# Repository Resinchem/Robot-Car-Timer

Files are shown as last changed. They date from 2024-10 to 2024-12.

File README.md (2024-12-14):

## Robot Car Race Timer System
The project was developed as a simple automatic timing system for 6th grade computer science robot car races, but has many other potential uses.

MainPage

It uses and ESP32, MAX7219 display and VL53L0X sensors to determine when an object crosses the start or finish line and starts or stops the timer (with 0.1 second resolution), shown on the matrix display.  Use of the VL53L0X distance sensors instead of motion allows movement around and near the 'race course' without triggering the sensors.  Optional LED lighting is also synced to the start, active and end race stages.

The full version includes WiFi onboarding, a web interface for some settings and over-the-air (OTA) updates for future firmwware releases.  Note that support for the no-WiFi version was dropped beginning with version 0.22.  If you truly need a version that does not require or use WiFi, please see [release 0.21](https://github.com/Resinchem/Robot-Car-Timer/releases/tag/v0.21), which was the last version that supported a -noWiFi version.

You can watch a video on the build process here: [ESP32 Build: An Automated Timing System for Robot Racers](https://youtu.be/EBmh5WEJYhU)

Please refer to the [wiki](https://github.com/Resinchem/Robot-Car-Timer/wiki) for full information, including installation, setup, options and use of the system.

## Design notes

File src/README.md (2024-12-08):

### If you just want to install the firmware on your ESP32, you do not need to download the source code!
Just download the latest **RobotCarTimer_vx.xx_ESP32.bin** file from the [Releases page](https://github.com/Resinchem/Robot-Car-Timer/releases) and follow the installation and instructions that are found in the [wiki](https://github.com/Resinchem/Robot-Car-Timer/wiki).  Please try the steps in the wiki before posting questions about how to install the firmware.

## Source Code
Two versions of the source code are available.  _You only need one source code file!_

**racecar_timer.ino**

_This is the recommended version._ It contains all the features, including the ability to make changes to some options and settings using a web interface and to perform over-the-air (OTA) updates of the firmware wirelessly.  This is the only version supported after v0.21.

**racecar_nowifi.ino** (v0.21 and earlier only)

This version should only be used if the intended installation location does not have WiFi available.  It obviously does not include any sort of web interface and therefore any changes to the settings and options require editing the source code, recompiling and then uploading via the Arduino IDE or other compatible application.  And since over-the-air updates are not available without WiFi, each update or change requires connecting the controller to a PC/USB port for uploading.  _Releases of the software after v0.21 do not include a non-WiFi version!_

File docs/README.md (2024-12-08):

### This document contains much of the same information that can be found in the Wiki.

It is provided as a dowloadable version for potential use or easier access when building/using the system.  This document is current as of the v0.25 release **but may not be updated with future versions**.

Note that you must download and/or open this document outside of Github for any of the embedded links in the document to function.  This includes the links found in the table of contents.

#### Always refer to the Wiki and version release notes for the most current information!

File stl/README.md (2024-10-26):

### 3D Printed Parts
A few optional 3D printed enclosure design files are provided here.  Note that use of 3D printed parts is _entirely optional_ and is not required for system functionality.  You can substitue project boxes or omit enclosures altogether.

All enclosures were printed with PLA.  **Supports are highly recommended for all parts**.

#### Controller Enclosure
ControllerEnclosure_Small

A simple enclosure for the ESP32 controller.  Designed for a standard 1/2 size ElectroCookie solderable breadboard with height to accommodate pin headers.  Mounting posts that accept M2 screws elevates the ElectroCookie board so that wiring may be completed on the top or bottom of the board.

#### MAX7219 Timer Enclosure
TimerEnclosure_small

The timer enclosure not only houses the MAX7219 dot-matrix display, but also the push buttons and toggle switch for the system.  The MAX7219 should pressure fit, but if it is loose or tends to fall out, just a couple of spots of hot glue on the vertical back supports will keep the display in place but still allow it to be removed if necessary.

#### VL53L0X Mount
VL53L0X_Mount_small

This mount provides a mounting bracket that allows the VL53L0X to be mounted while still allowing vertical and horizontal adjustments so that sensor can be precisely aligned with the start/finish lines.  It is a slightly remixed version of the [original version by Speedfreek01 via Thingiverse](https://www.thingiverse.com/thing:4511170).

_These files are provided "as-is" and unfortunately I cannot modify or print parts for individual use._

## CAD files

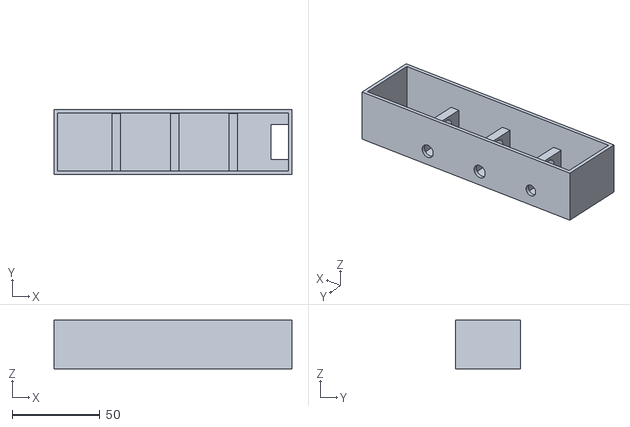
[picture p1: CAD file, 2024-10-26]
stl/MAX7219 Timer Enclosure.stl
136.0 x 37.0 x 28.0

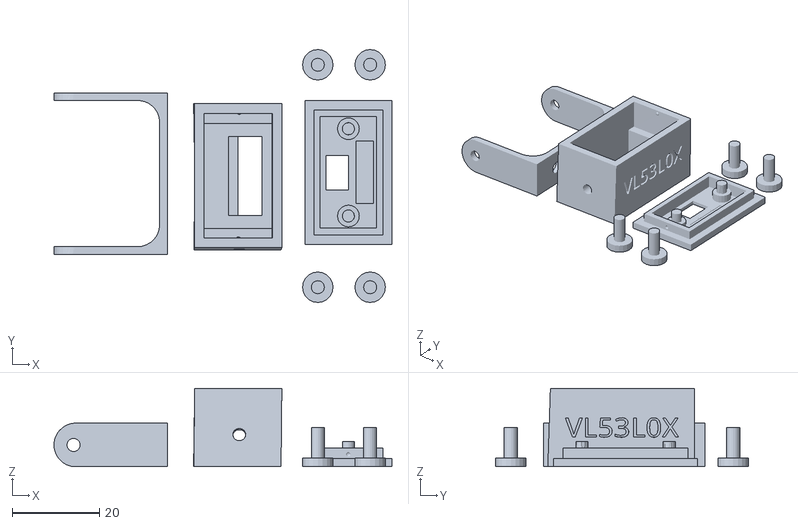
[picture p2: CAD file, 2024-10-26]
stl/VL53L0x Mount v3.stl
77.5 x 58.0 x 18.0

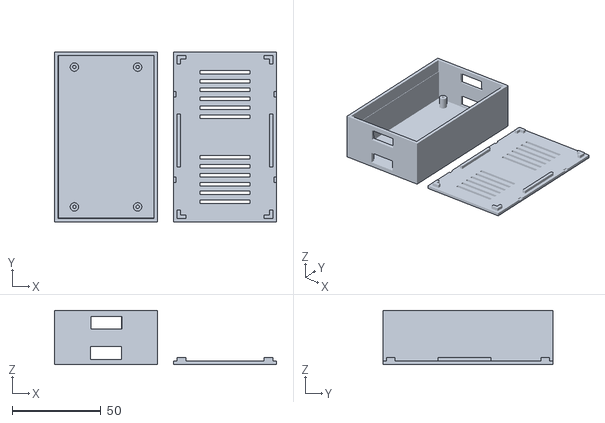
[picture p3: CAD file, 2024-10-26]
stl/Controller Enclosure V3.stl
125.0 x 96.0 x 30.5

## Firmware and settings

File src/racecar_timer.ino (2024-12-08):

/* ===============================================================
   Race Car Timer System
   After successful wifi join, the following can be used from web browser:
    http://ip_address/   - Shows current Device Name, MAC, IPAddress - also list the following commands:
    http://ip_address/restart - Just reboots the board
    http://ip_address/reset - Clears config and relaunches hotspot/config page (can be used to change WiFi or name)
    http://ip_address/otaupdate - puts the system into Arduino OTA mode for wirelessly flashing new firmware
    http://ip_address/leds&brightness=x - change LED brightness.  x = 1 to 10.
    http://ip_address/timer&brightness=x - change timer brightness. x = 1 to 10.

    Version: 0.25
   ===============================================================*/
//Basic Web and Wifi
#include <WiFi.h>
#include <ESPmDNS.h>
#include <WebServer.h>
#include <FS.h>                         //Arduino ESP32 Core - Handles filesystem functions (read/write config file)
#include <LittleFS.h>
#include <ArduinoJson.h>                //Needed for WiFi onboarding: https://arduinojson.org/ (v7.2.0)
#include <Wire.h>                       //I2C - distance sensors (ESP Core)
#include <SPI.h>                        //SPI - Timer display (ESP Core)
//OTA and Firmware Update Libraries
#include <WiFiUdp.h>
#include <ArduinoOTA.h>                 //OTA Updates: https://github.com/jandrassy/ArduinoOTA (v1.0.12)
#include <ElegantOTA.h>                 //Web based firmware OTA Update:  https://github.com/ayushsharma82/ElegantOTA/ (v3.1.5)
//VL53L0X
#include <VL53L0X.h>                    //VL53L0X ToF Sensor https://github.com/pololu/vl53l0x-arduino (v1.3.1) 
//MAX7219 Display
#include <MD_MAX72xx.h>                 //MAX7219 Matrix (SPI) https://github.com/JemRF/max7219 (installed as dependency of MD_Parola) (v3.5.1)
#include <MD_Parola.h>                  //MAX7219 Matrix https://github.com/MajicDesigns/MD_Parola (v3.7.3)
//LEDs
//LED-related Libraries
#define FASTLED_INTERNAL                // Suppress FastLED SPI/bitbanged compiler warnings
#include <FastLED.h>                    // v3.7.1 LED Strip Control: https://github.com/FastLED/FastLED (v3.7.1)

#define VERSION "v0.25 (ESP32)"
#define APPNAME "RACECAR TIMER"
#define WIFIMODE 2                      // 0 = Only Soft Access Point, 1 = Only connect to local WiFi network with UN/PW, 2 = Both
#define SERIAL_DEBUG 0                  // 0 = Disable (must be disabled if using RX/TX pins), 1 = enable
#define FORMAT_LITTLEFS_IF_FAILED true

// ======================================================
//  Change or update these values for your build/options
// ======================================================
//Pin Defintions - update if your build is different
#define BUS1_SDA 21                     //I2C Bus 1 Data (ToF start sensor)
#define BUS1_SCL 22                     //I2C Bus 1 Clock (ToF start sensor)
#define BUS2_SDA 17                     //I2C Bus 2 Data (ToF end sensor)
#define BUS2_SCL 19                     //I2C Bus 2 Clock (ToF end sensor)
#define SPI_DIN 23                      //SPI Data In (LED timer matrix )
#define SPI_CLK 18                      //SPI Clock 
#define SPI_CS 5                        //SPI Chip Select
#define LED_DATA_PIN 16                 //Data line for LED strip lighting
#define BUTTON_RESET 26                 //Timer button - Reset
#define BUTTON_START_STOP 25            //Timer button - Manual time start/stop
#define TOGGLE_AUTO 27                  //Toggle switch - auto timing mode
#define TOGGLE_MANUAL 13                //Toggle switch - manual timing mode

//Timing & System Options - can also be updated/saved via web settings
#define USE_TENTHS true                   //Setting to false will only show minutes and whole seconds on timer
#define MAX_RACE_TIME 599                 //Max race time in seconds (599 max when using tenths, 5999 otherwise)
#define USE_LEDS true                     //Set to false if not using LED strips (changing this overrides num LEDs)
#define DEFAULT_TIMER_INTENSITY 3         //Matrix timer starting brightness (0-10). Can be changed via URL command.
//Sensor Distances (in mm) and debounce
#define START_SENSOR_DIST 500             //Should be distance (mm) from start line sensor to the opposite edge of race track
#define END_SENSOR_DIST 500               //Should be distance (mm) from end line sensor to the opposite edge of race track
#define START_SENSOR_DEBOUNCE 2           //Debounce value for start sensor (valid values 1-5)
#define END_SENSOR_DEBOUNCE 2             //Debounce value for end sensor (valid values 1-5)
//LED Lighting Strips
#define NUM_LEDS 500                       //Number of LEDs (one side only - max - will be updated via onboarding)
#define MILLIAMP_MAX 15000                 //Max milliamp draw permitted by the LEDs
#define DEFAULT_LED_BRIGHTNESS 125         //LED Strip brightness (0-255) - read from config file and set during onboarding
//==================================================

//================================================================================
// Do not change any values below unless you are SURE you know what you are doing!
//================================================================================
//Peripheral Defines
//MAX7219 Display
#define MAX_DEVICES 4                      //MAX7219 - Number of controllers
#define HARDWARE_TYPE MD_MAX72XX::FC16_HW  //MAX7219 Matrix
#define NUMELEMENTS(x) sizeof(x)/sizeof(x[0])  // Number of elements in arrays


//Boot indication variables
bool useOnboardLED = true;                 //Use onboard LED to show successful wifi join and config file creation 
int blinkLED = 0;                          //Counter for above.  LED will blink 5 times and remain on if useOnboardLED is true
bool useLEDs = USE_LEDS;                   //LED strips will be disabled if num of LEDs is set to zero during onboarding.
bool showAddressOnBoot = true;             //Output device IP address on MAX7219 on normal boot

//Local Variables (wifi/onboarding)
String deviceName = "RaceTimer";           //Default Device Name - 16 chars max, no spaces. 
String wifiHostName = deviceName;
String wifiSSID = "";
String wifiPW = "";
byte macAddr[6];                           //Array of device mac address as hex bytes (reversed)
String strMacAddr;                         //Formatted string of device mac address
String baseIPAddress;                      //Device assigned IP Address
bool onboarding = false;                   //Will be set to true if no config file or wifi cannot be joined

//Local Variables (Settings & options)
int numLEDs = 30;
unsigned int ledBrightness = DEFAULT_LED_BRIGHTNESS;
int milliAmpsMax = 8000;
byte timerBrightness = DEFAULT_TIMER_INTENSITY;      //This is not part of onboarding, but can be changed via URL command (valid 1-10).
bool showTenths = USE_TENTHS;                        //true = show tenths of a second, false = show only minutes/seconds
bool invertTimer = false;                            //Flip timer display horizontally (so it can be mounted upside down)
unsigned long maxRaceTime = (MAX_RACE_TIME) * 1000;  //Just a default starting value.  Actual value updated in Setup from config file
unsigned int startSensorDist = START_SENSOR_DIST;    //Max trigger distance for start line sensor (in mm)
unsigned int endSensorDist = END_SENSOR_DIST;        //Max trigger distance for finish line sensor (in mm)

//OTA Variables
String otaHostName = deviceName + "OTA";   //Will be updated by device name from onboarding + _OTA
bool ota_flag = true;                       // Must leave this as true for board to broadcast port to IDE upon boot
uint16_t ota_boot_time_window = 2500;       // minimum time on boot for IP address to show in IDE ports, in millisecs
uint16_t ota_time_window = 20000;           // time to start file upload when ota_flag set to true (after initial boot), in millsecs
uint16_t ota_time_elapsed = 0;              // Counter when OTA active
uint16_t ota_time = ota_boot_time_window;

//Misc. Application Variables
bool systemStandby = false;                 //Toggle - center pos: puts system in standby (stops processes, turns off timer/LEDs)
bool timerAuto = true;                      //Toggle - auto/manual timing     
bool timerRunning = false;
bool timerComplete = false;
bool bootUp = true;
unsigned long prevTime = 0;
unsigned long elapsedTime = 0;

//Sensor Debouncing (longer cables/smaller gauge wire may result in noisy signals)
byte startTriggerCount = 0;
byte endTriggerCount = 0;
byte startTriggerMax = START_SENSOR_DEBOUNCE;  //Start Sensor debounce max count
byte endTriggerMax = END_SENSOR_DEBOUNCE;     //End Sensor debounce max count

//Manual Start/Stop button debouncing
unsigned long lastDebounceTime = 0;         
unsigned long debounceDelay = 75;           //millisecond delay
int startButtonState;                       //For tracking state
int lastButtonState = HIGH;                 //Set initial state (HIGH = not pressed)

//Timing Mode variables
int oldAutoState;
int oldManualState;
bool poweredDown = false;
String lastRaceTime = "0:00.0";

//LED Color Definitions - values can be changed via web settings
CRGB ledColorReady = CRGB::Yellow;
CRGB ledColorRaceSeg1 = CRGB::Blue;
CRGB ledColorRaceSeg2 = CRGB::White;
CRGB ledColorEnd = CRGB::Green;
CRGB ledColorExpired = CRGB::Red;
//LED Color indices for web drop downs (match to colors above from array)
byte webColorReady = 8;     //Yellow
byte webColorRaceSeg1 = 1;  //Blue
byte webColorRaceSeg2 = 0;  //White
byte webColorEnd = 3;       //Green
byte webColorExpired = 7;   //Red

//Define Color Arrays
//If adding new colors, increase array sizes and add to void defineColors()
CRGB ColorCodes[10];
String WebColors[10];

//Intialize web server
WebServer server(80);

//Instantiate sensors, display and LEDs
VL53L0X startTimer;
VL53L0X endTimer;
TwoWire bus1 = TwoWire(0);     //I2C Bus 1
TwoWire bus2 = TwoWire(1);     //I2C Bus 2
MD_Parola timerDisplay = MD_Parola(HARDWARE_TYPE, SPI_DIN, SPI_CLK, SPI_CS, MAX_DEVICES);  //SPI LED Display (Type, DIN, SCL, CS, NumDevices)
CRGB LEDs[NUM_LEDS];

//===========================
// Populate Color Arrays
//===========================
void defineColors() {
  //  Increase array sizes in definitions if adding new
  //  Color must be defined as a CRGB::Named Color or as a CRGB RGB value: CRGB(r, g, b);
   ColorCodes[0] = CRGB::White;
   ColorCodes[1] = CRGB::Blue;
   ColorCodes[2] = CRGB::Cyan;
   ColorCodes[3] = CRGB::Green;
   ColorCodes[4] = CRGB::Magenta;
   ColorCodes[5] = CRGB::Orange;
   ColorCodes[6] = CRGB::Pink;
   ColorCodes[7] = CRGB::Red;
   ColorCodes[8] = CRGB::Yellow;
   ColorCodes[9] = CRGB::Black;
   
   WebColors[0] = "White";
   WebColors[1] = "Blue";
   WebColors[2] = "Cyan";
   WebColors[3] = "Green";
   WebColors[4] = "Magenta";
   WebColors[5] = "Orange";
   WebColors[6] = "Pink";
   WebColors[7] = "Red";
   WebColors[8] = "Yellow";
   WebColors[9] = "Black (off)";
}

//============================
// Read config file from flash (LittleFS)
//============================
void readConfigFile() {

  if (LittleFS.begin(FORMAT_LITTLEFS_IF_FAILED)) {  
    #if defined(SERIAL_DEBUG) && (SERIAL_DEBUG == 1)
      Serial.println("mounted file system");
    #endif
    if (LittleFS.exists("/config.json")) {
      //file exists, reading and loading
      #if defined(SERIAL_DEBUG) && (SERIAL_DEBUG == 1)
        Serial.println("reading config file");
      #endif
      File configFile = LittleFS.open("/config.json", "r");
      if (configFile) {
        #if defined(SERIAL_DEBUG) && (SERIAL_DEBUG == 1)
          Serial.println("opened config file");
        #endif
        size_t size = configFile.size();
        // Allocate a buffer to store contents of the file.
        std::unique_ptr<char[]> buf(new char[size]);

        configFile.readBytes(buf.get(), size);
        DynamicJsonDocument json(1024);
        auto deserializeError = deserializeJson(json, buf.get());
        serializeJson(json, Serial);
        if ( ! deserializeError ) {

          #if defined(SERIAL_DEBUG) && (SERIAL_DEBUG == 1)
            Serial.println("\nparsed json");
          #endif
          // Read values here from LittleFS (v0.42 - add defaults for all values in case they don't exist to avoid potential boot loop)
          //DON'T NEED TO STORE OR RECALL WIFI INFO - Written to flash automatically by library when successful connection.
          deviceName = json["device_name"] | "RaceTimer";
          numLEDs = json["led_count"] | 30;
          ledBrightness = json["led_brightness"] | 125;
          milliAmpsMax = json["milli_amps_max"] | 2500;
          timerBrightness = json["timer_brightness"] | 3;
          showTenths = json["show_tenths"] | true;
          invertTimer = json["invert_timer"] | false;
          maxRaceTime = json["max_race_time"] | 120;
          startSensorDist = json["start_sensor_dist"] | 500; 
          startTriggerMax = json["start_trigger_max"] | 2;
          endSensorDist = json["end_sensor_dist"] | 500;
          endTriggerMax = json["end_trigger_max"] | 2;
          webColorReady = json["color_ready"] | 8;
          webColorRaceSeg1 = json["color_race_seg1"] | 1;
          webColorRaceSeg2 = json["color_race_seg2"] | 0;
          webColorEnd = json["color_end"] | 3;
          webColorExpired = json["color_expired"] | 7; 
          
          ledColorReady = ColorCodes[webColorReady];
          ledColorRaceSeg1 = ColorCodes[webColorRaceSeg1];
          ledColorRaceSeg2 = ColorCodes[webColorRaceSeg2];
          ledColorEnd = ColorCodes[webColorEnd];
          ledColorExpired = ColorCodes[webColorExpired];
        
          wifiHostName = deviceName;
          otaHostName = deviceName + "_OTA";
 
        } else {
          #if defined(SERIAL_DEBUG) && (SERIAL_DEBUG == 1)
            Serial.println("failed to load json config");
          #endif
          onboarding = true;
        }
        configFile.close();
      }
    } else {
        // No config file found - set to onboarding
        onboarding = true;
    }
          
    LittleFS.end();    //End - need to prevent issue with OTA updates
  } else {
    //could not mount filesystem
    #if defined(SERIAL_DEBUG) && (SERIAL_DEBUG == 1)
      Serial.println("failed to mount FS");
      Serial.println("LittleFS Formatted. Restarting ESP.");
      //ESP.restart();
    #endif
    
  }
}
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
void loop() {
  //Handle OTA updates when OTA flag set via HTML call to http://ip_address/otaupdate
  if (ota_flag) {
    showOTA(true);
    uint32_t ota_time_start = millis();
    while (ota_time_elapsed < ota_time) {
      ArduinoOTA.handle();  
      ota_time_elapsed = millis()-ota_time_start;   
      delay(10); 
    }
    ota_flag = false;
    showOTA(false);
  }
 
  //Handle any web calls
  server.handleClient();

  if (!onboarding) {
    //Only execute loop and rest of app if onboarding has been completed
    int startDist = 0;
    int endDist = 0;
    ElegantOTA.loop();    
    //Blink onboard LED three times then remain on - should only start after successful onboard
    if (useOnboardLED) {
      while (blinkLED < 3) {
        digitalWrite(2, HIGH);
        delay(500);
        yield();
        digitalWrite(2, LOW);
        delay(500);
        yield();
        blinkLED ++;
        #if defined(SERIAL_DEBUG) && (SERIAL_DEBUG == 1)
          Serial.begin(115200);
          Serial.println("Blink");
        #endif
      }
      digitalWrite(2, HIGH);
    } else {
      digitalWrite(2, LOW);
    } 
    //REST OF MAIN LOOP HERE
    unsigned long currentMillis = millis();
    //Check for state change of toggle switch/timing mode
    int curAuto = digitalRead(TOGGLE_AUTO);
    int curManual = digitalRead(TOGGLE_MANUAL);
    if ((curAuto != oldAutoState) || (curManual != oldManualState)) {
      setTimingMode();
    }
    if (systemStandby) {
      if (!poweredDown) {
        timerDisplay.displayClear();
        timerDisplay.print("Stndby");
        fill_solid(LEDs, numLEDs, CRGB::Black);
        FastLED.show();
        delay(1000);
        timerDisplay.displayClear();
        poweredDown = true;
      }
    } else {
      if ((bootUp) || (poweredDown)) {
        bootUp = false;
        poweredDown = false;
        resetTimer();
      }
      //Check for timer button presses - Currently, only the reset button is checked. Still need code for manual start/stop feature
      if (!digitalRead(BUTTON_RESET)) {
        resetTimer();
        #if defined(SERIAL_DEBUG) && (SERIAL_DEBUG == 1)
          Serial.println("System Reset");
        #endif
      } else if (!timerAuto) {
        //---- MANUAL TIMING -------- (using pushbutton)
        //Only check start/stop button in manual mode
        int reading = digitalRead(BUTTON_START_STOP);
        //Debounce
        if (reading != lastButtonState) {
          lastDebounceTime = millis(); 
        }
        if ((millis() - lastDebounceTime) > debounceDelay) {
          if (reading != startButtonState) {
            startButtonState = reading;
            if (!startButtonState) {
              if ((!timerRunning) && (!timerComplete)) {
                //Start timer
                startTime();
                prevTime = millis();
                currentMillis = prevTime;
                elapsedTime = 0;
              } else if ((timerRunning) && (!timerComplete)) {
                //Stop timer
                stopTime();
              }
            }
          }
        }
        lastButtonState = reading;
      } else {
        //---- AUTOMATIC TIMING ------- (using sensors)
        //Get sensor readings
        startDist = startTimer.readRangeContinuousMillimeters();
        endDist = endTimer.readRangeContinuousMillimeters();
        //Check for starting sensor break if timer not running
        //System ready/standby: timerRunning FALSE and timerComplete FALSE
        //System in progress: timerRunning TRUE and timerComplete FALSE
        //Race Finished: timerRunning FALSE and timerComplete TRUE
        if ((!timerRunning) && (!timerComplete)) {
          if (startDist < startSensorDist) {
            startTriggerCount++;
            if (startTriggerCount >= startTriggerMax) {
            //start timer and turn LEDs to race pattern
              startTime();
              prevTime = millis();
              currentMillis = prevTime;
              elapsedTime = 0;
              startTriggerCount = 0;
            }
          } else {
            startTriggerCount = 0;
          }
        } else if ((timerRunning) && (!timerComplete)) {
          if (endDist < endSensorDist) {
            endTriggerCount++;
            if (endTriggerCount >= endTriggerMax) {
              stopTime();
              endTriggerCount = 0;
            }
          } else {
            endTriggerCount = 0;
          }
        }
      }
      //Update time 
      if ((timerRunning) && (!timerComplete)) {
        if ((showTenths) && ((currentMillis - prevTime) >= 100)) {
          prevTime = currentMillis;
          elapsedTime = elapsedTime + 100;
          updateTimer();
          #if defined(SERIAL_DEBUG) && (SERIAL_DEBUG == 1)
            Serial.print("Elapsed Time (s): ");
            Serial.print(elapsedTime / 1000);
            Serial.print("  Start Dist: ");
            Serial.print(startDist);
            Serial.print("  End Dist: ");
            Serial.println(endDist);
          #endif
          //}
        } else if ((currentMillis - prevTime) >= 1000) {
          prevTime = currentMillis;
          elapsedTime = elapsedTime + 1000;
          updateTimer();
          #if defined(SERIAL_DEBUG) && (SERIAL_DEBUG == 1)
            Serial.print("Elapsed Time (ms): ");
            Serial.print(elapsedTime / 1000);
            Serial.print("  Start Dist: ");
            Serial.print(startDist);
            Serial.print("  End Dist: ");
            Serial.println(endDist);
          #endif

        }
      }
    }  
  }
}

// ========================
//  Timer Functions
// ========================
void setTimingMode() {
  //Sets timing mode (standby, auto, manual) based on toggle switch pos
  int curAuto = digitalRead(TOGGLE_AUTO);
  int curManual = digitalRead(TOGGLE_MANUAL);
  if (!curAuto) {
    timerAuto = true;
    systemStandby = false;
  } else if (!curManual) {
    timerAuto = false;
    systemStandby = false;
  } else {
    //Toggle in center pos - both GPIO pins high
    systemStandby = true;
  }
  oldAutoState = curAuto;
  oldManualState = curManual;
}

void startTime() {
  timerDisplay.displayClear();
  timerDisplay.setTextAlignment(PA_LEFT);
  if (showTenths) {
    timerDisplay.print(" 0:00.0");  //v0.12 tenths of a second
  } else {
    timerDisplay.print(" 00:00");
  }
  if (useLEDs) {
    showRaceLEDs();
  }
  timerRunning = true;
  #if defined(SERIAL_DEBUG) && (SERIAL_DEBUG == 1)
    Serial.println("Timer started.");
  #endif
}

void stopTime() {
  //stop timer and set end LED color
  if (useLEDs) {
    //fill_solid(LEDs, numLEDs, CRGB::Green);
    fill_solid(LEDs, numLEDs, ledColorEnd);
    FastLED.show();
  }
  timerComplete = true;
  timerRunning = false;
  #if defined(SERIAL_DEBUG) && (SERIAL_DEBUG == 1)
    Serial.println("Timer stopped.");
  #endif

}

void resetTimer() {
  timerRunning = false;
  timerComplete = false;
  if (useLEDs) {
    fill_solid(LEDs, numLEDs, ledColorReady);
    FastLED.show();
  }
  timerDisplay.setTextAlignment(PA_CENTER);
  timerDisplay.displayClear();
  timerDisplay.print("Ready");
}
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
